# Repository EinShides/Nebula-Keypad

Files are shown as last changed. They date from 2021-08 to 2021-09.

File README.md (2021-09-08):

A small 3 key keypad with a rotary encoder and lcd display. The case is 3d printable and designed to work with m2 threaded inserts (4-5mm). Uses USB C, ESD protection, and GeonWorks tadpole mount. Currently a BOM is in the works.

THIS KEYPAD HAS NOT BEEN TESTED YET. 

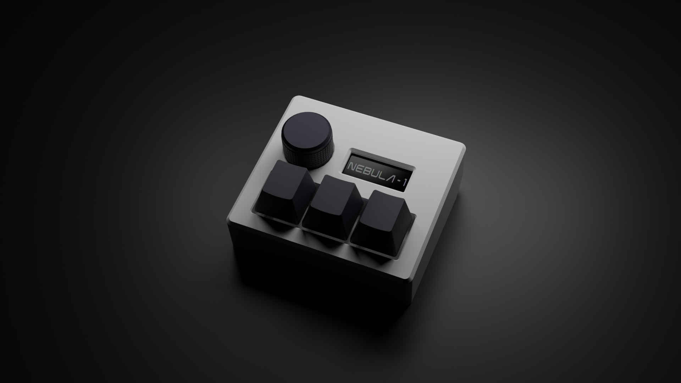
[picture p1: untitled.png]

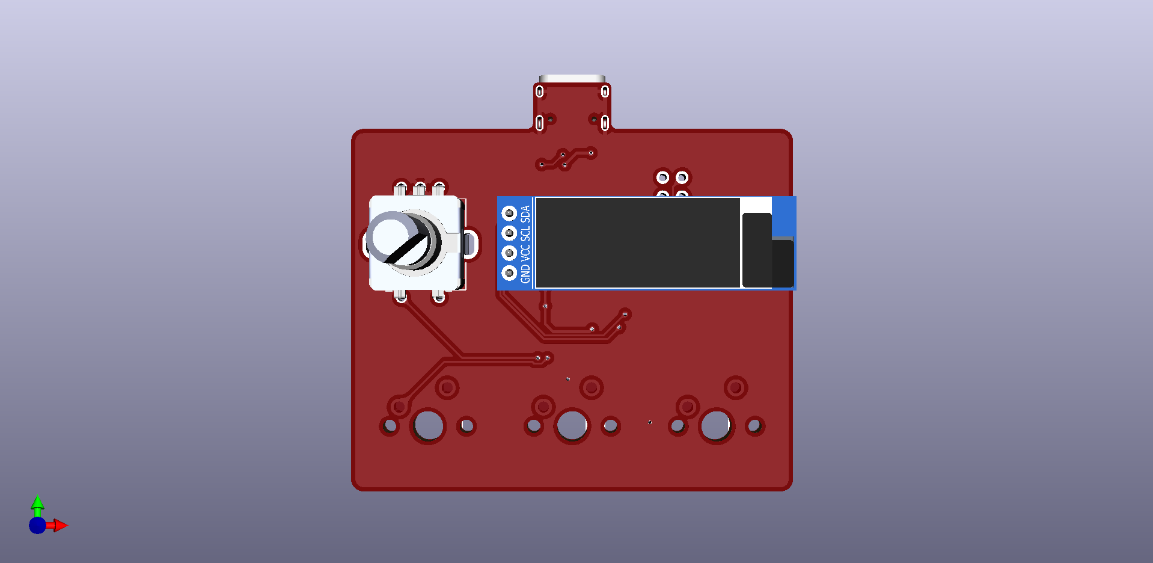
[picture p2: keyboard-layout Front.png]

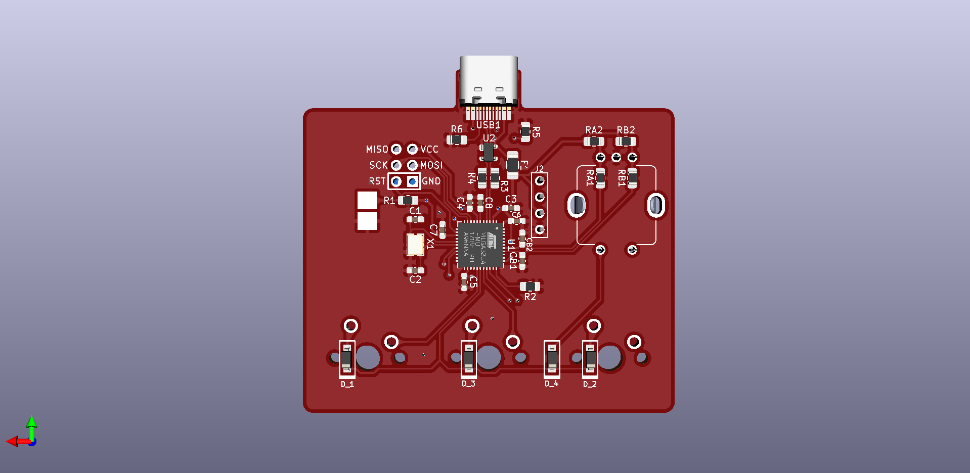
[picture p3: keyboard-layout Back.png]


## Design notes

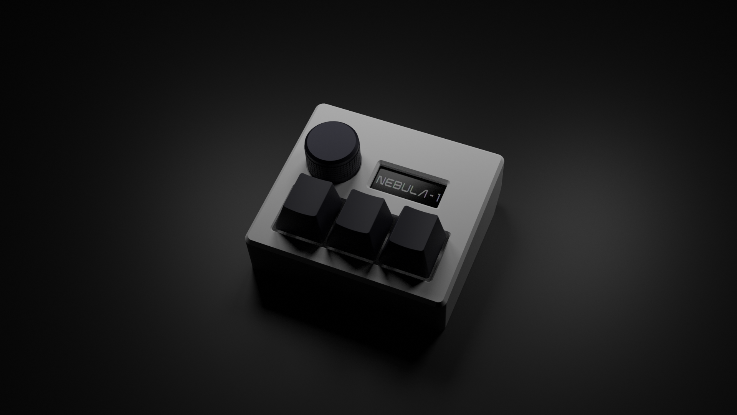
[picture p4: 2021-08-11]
Nebula.png

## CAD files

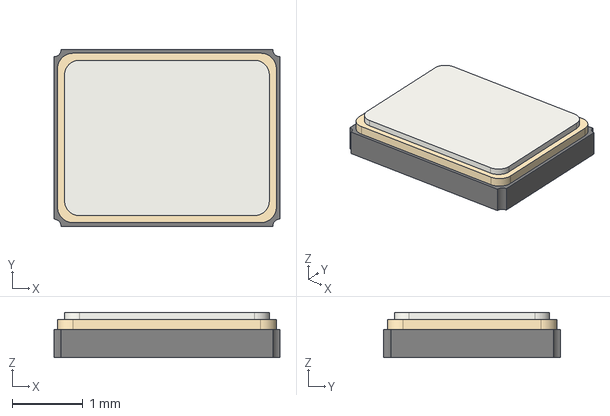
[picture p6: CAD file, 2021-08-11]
3d Component Models/Crystal_SMD_SeikoEpson_TSX3225-4Pin_3.2x2.5mm.step
3.20 x 2.50 x 0.64 mm

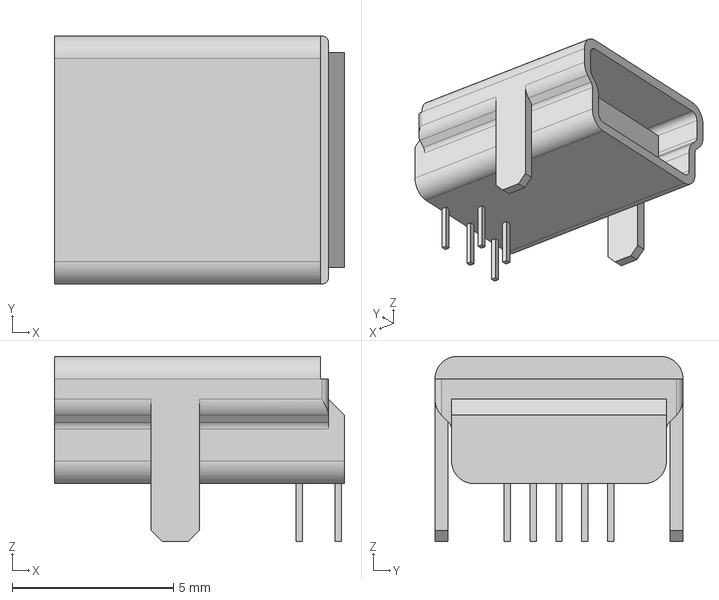
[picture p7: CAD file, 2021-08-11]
random-keyboard-parts.pretty-master/Molex-0548190519.step
9.00 x 7.70 x 5.75 mm

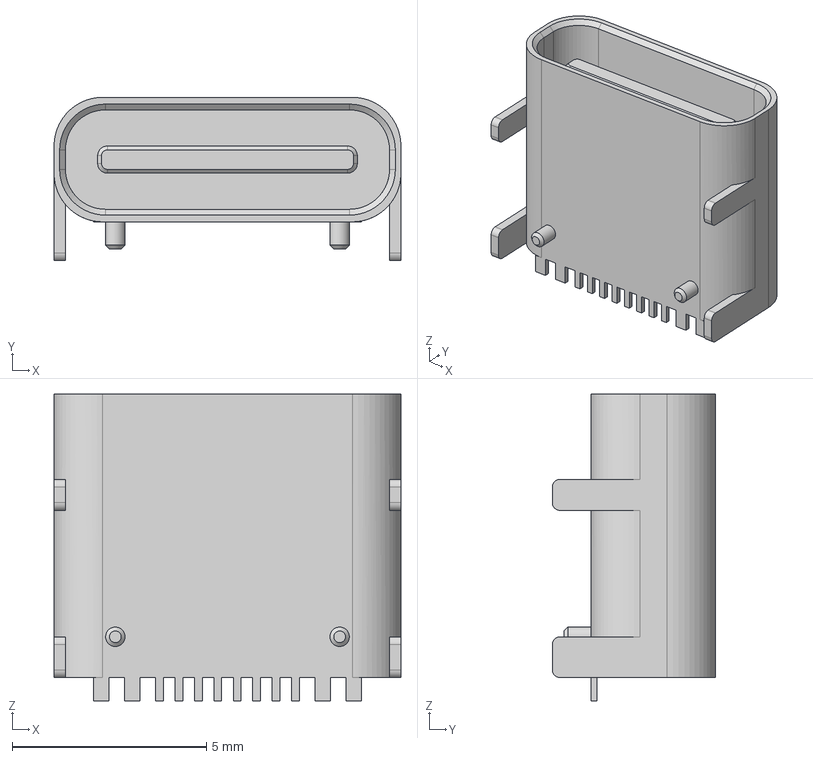
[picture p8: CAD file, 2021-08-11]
Type-C.pretty-master/HRO TYPE-C-31-M-12.step
8.94 x 4.21 x 7.90 mm

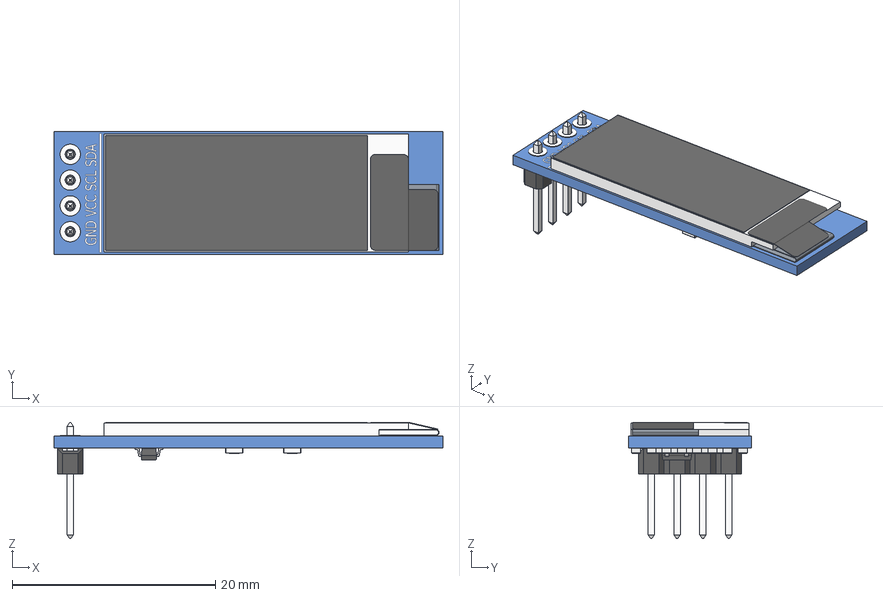
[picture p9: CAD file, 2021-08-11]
3d Component Models/OLED_0.91_128x32.stp
38.3 x 12.1 x 11.5 mm
OLED_0.91_128x32
Pin Header 4 x 1 TH 2.54mm Pitch
RESC-0603 x 13
2SD0601A

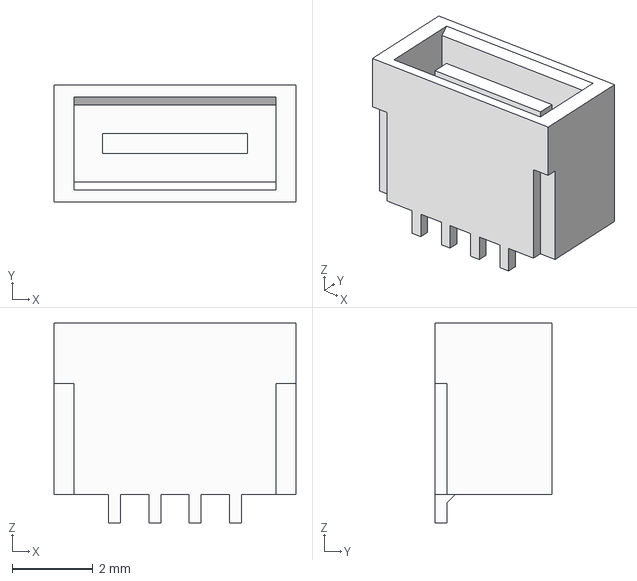
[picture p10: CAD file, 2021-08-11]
random-keyboard-parts.pretty-master/JST-SR-4.step
6.00 x 2.90 x 4.95 mm

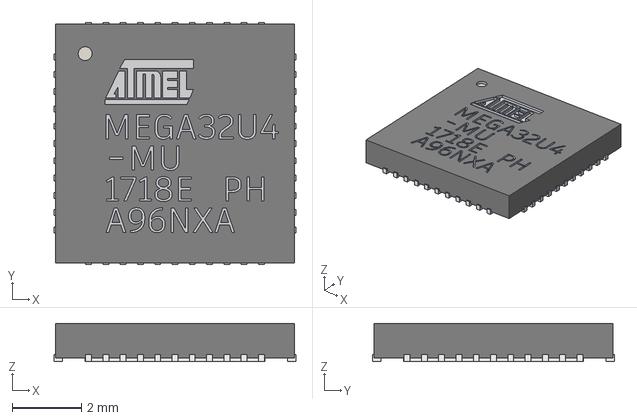
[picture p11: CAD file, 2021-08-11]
3d Component Models/QFN-44-1EP_7x7mm_P0.5mm_EP5.2x5.2mm.step
7.00 x 7.00 x 1.10 mm

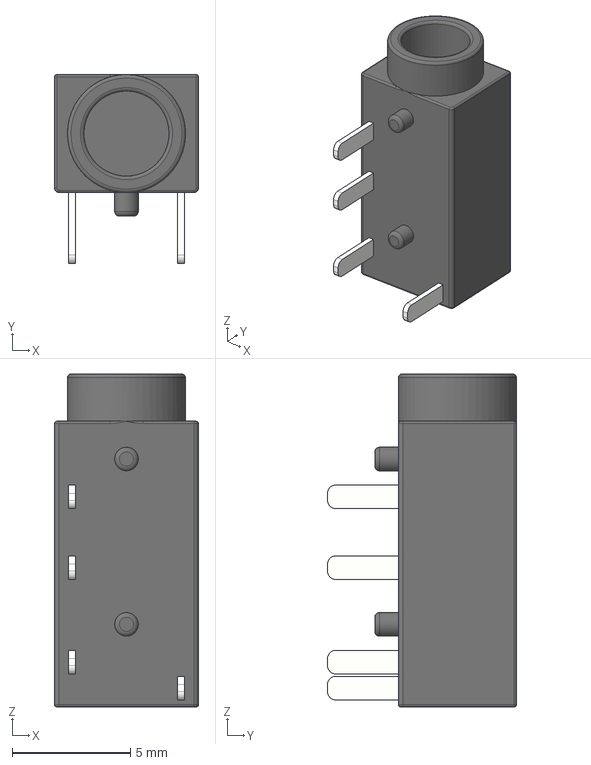
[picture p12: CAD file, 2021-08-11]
random-keyboard-parts.pretty-master/PJ-3200B.step
6.10 x 8.00 x 14.1 mm

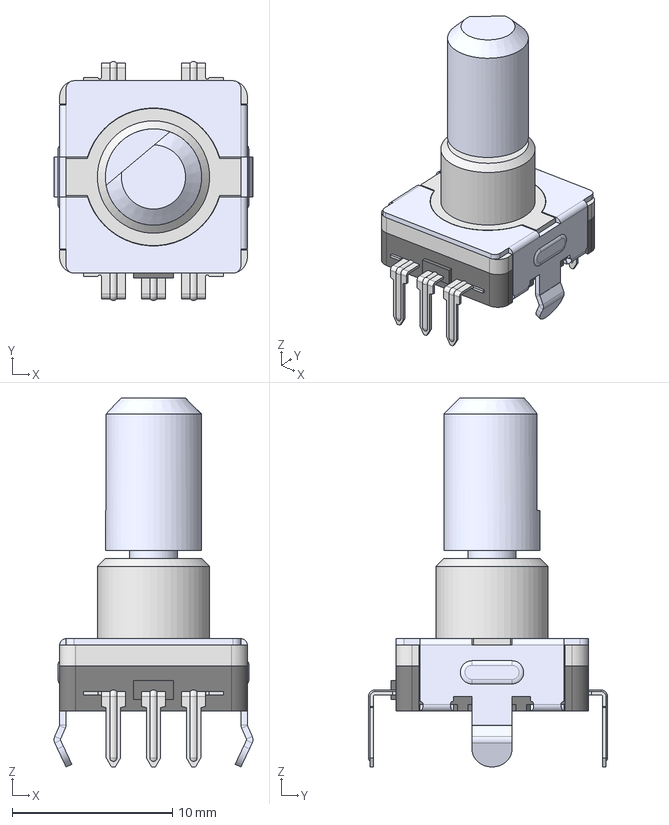
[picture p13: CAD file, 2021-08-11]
3d Component Models/EC11-THT-15F-black.step
12.4 x 14.9 x 23.0 mm
Lb5
15F
EC11-Housing-THT

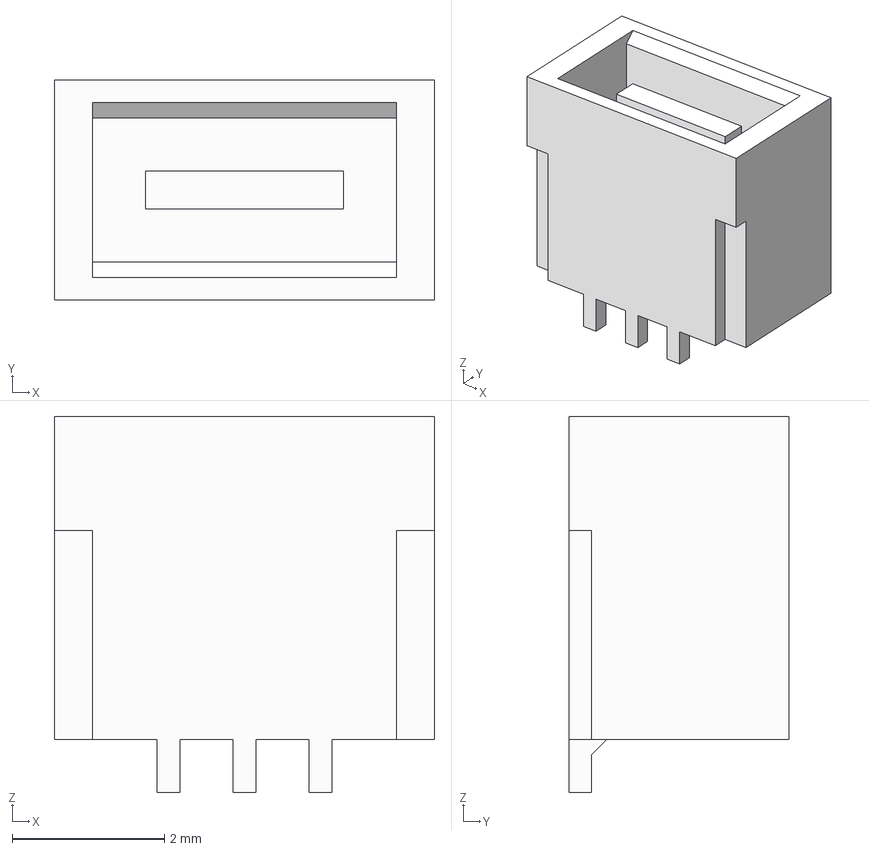
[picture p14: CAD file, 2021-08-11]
random-keyboard-parts.pretty-master/JST-SR-3.step
5.00 x 2.90 x 4.95 mm

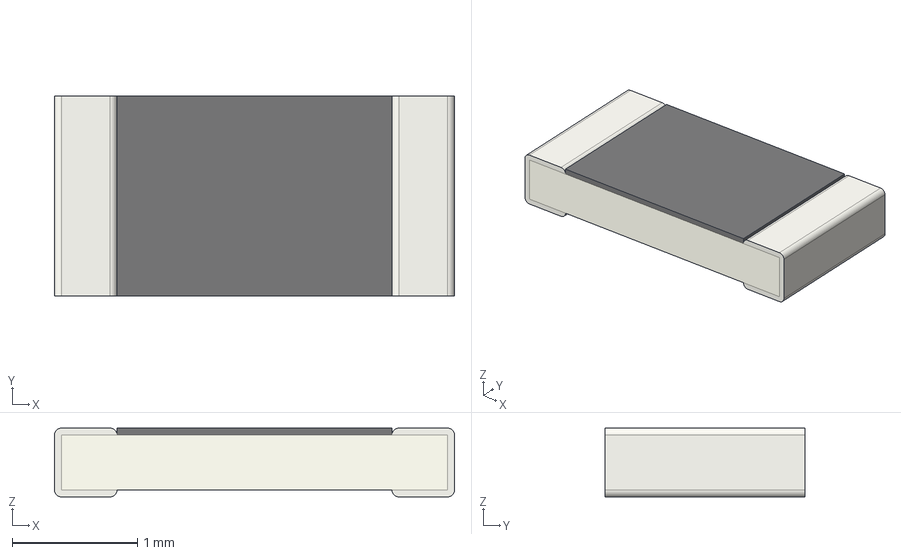
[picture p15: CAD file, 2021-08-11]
3d Component Models/Fuse_1206_3216Metric.step
3.20 x 1.60 x 0.55 mm

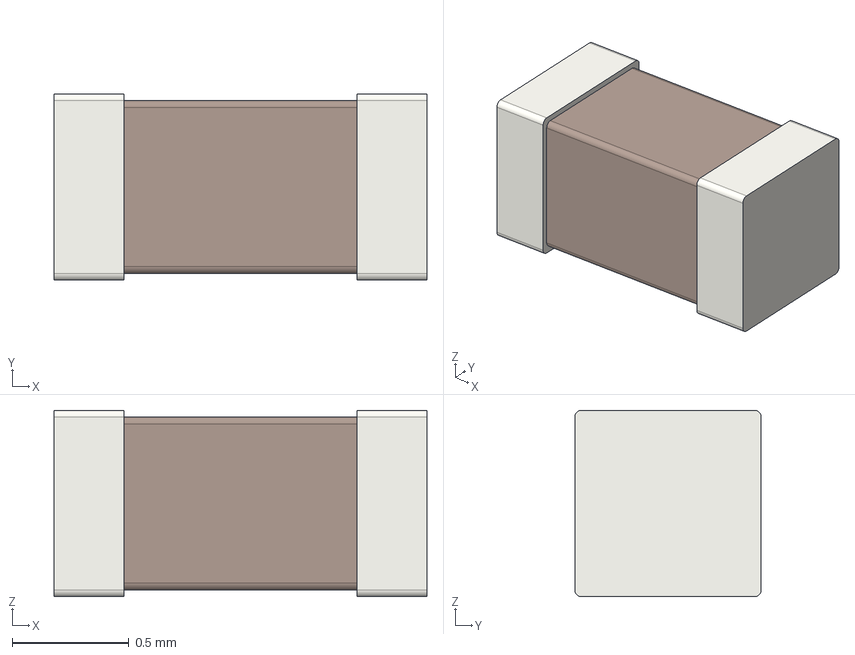
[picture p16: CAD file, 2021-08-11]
3d Component Models/C_0603_1608Metric.step
1.60 x 0.8 x 0.8 mm

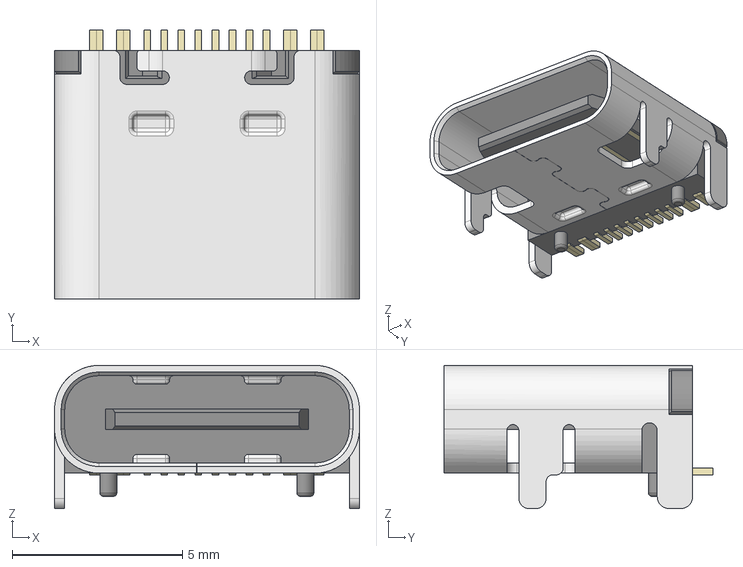
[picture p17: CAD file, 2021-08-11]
3d Component Models/HRO_TYPE-C-31-M-12.step
8.95 x 7.90 x 4.20 mm

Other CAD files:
kicad-footprints-master/Sources/Inductor_SMD/L_Coilcraft_LPS5030.FCStd
kicad-footprints-master/Sources/Package_LGA/Infineon_PG-LLGA-5-1.FCStd
kicad-footprints-master/Sources/Package_SON/X2SON-4_1x1mm_P0.65mm.fcstd
kicad-footprints-master/Sources/Package_TO_SOT_THT/sod-70_P5.08mm.fcstd
kicad-footprints-master/Sources/Inductor_SMD/L_Wuerth_WE-TPC-3816.FCStd
kicad-footprints-master/Sources/Package_TO_SOT_THT/sod-70.fcstd
3d Component Models/D_SOD-123.step
3d Component Models/R_0805_2012Metric.step

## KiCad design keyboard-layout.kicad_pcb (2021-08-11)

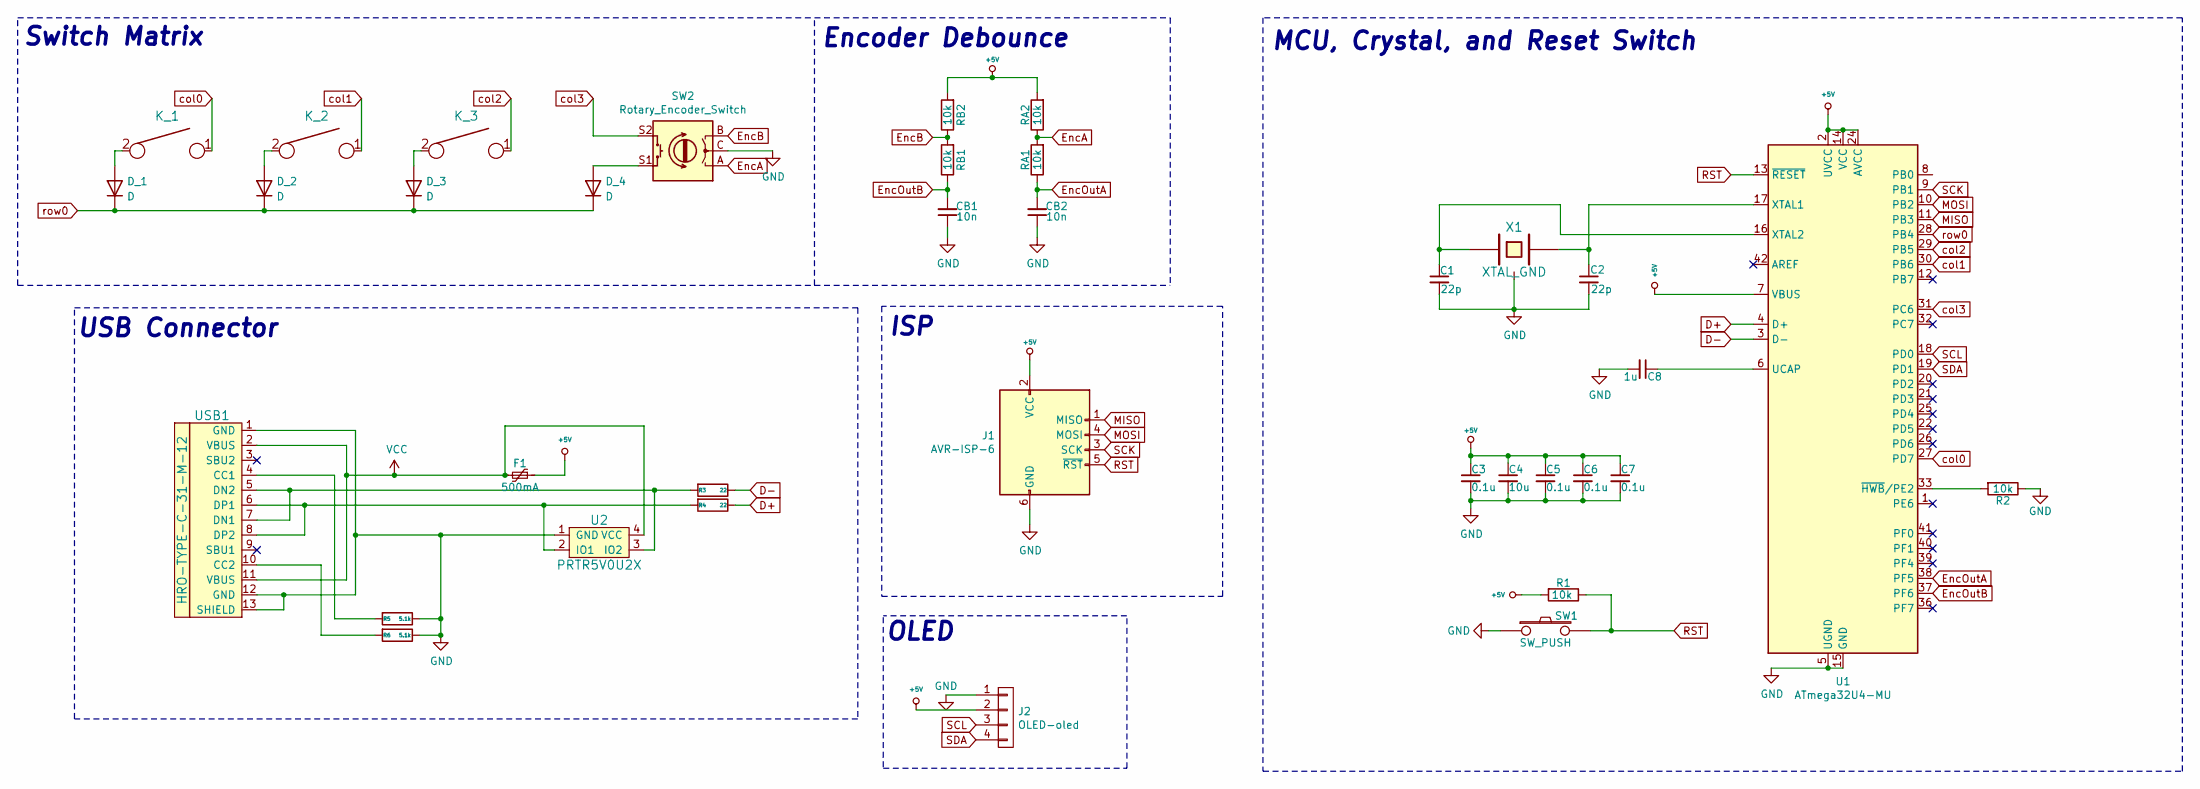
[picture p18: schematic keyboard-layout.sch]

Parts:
C1, C2: 22p; C_0603_1608Metric_Pad1.08x0.95mm_HandSolder; LCSC C1653
C3, C5, C6, C7: 0.1u; C_0603_1608Metric_Pad1.08x0.95mm_HandSolder; LCSC C24452
C4: 10u; C_0603_1608Metric_Pad1.08x0.95mm_HandSolder; LCSC C96446
C8: 1u; C_0603_1608Metric_Pad1.08x0.95mm_HandSolder; LCSC C15849
CB1, CB2: 10n; C_0603_1608Metric_Pad1.08x0.95mm_HandSolder; LCSC C15849
D_1, D_2, D_3, D_4: D; D_SOD123_hand; LCSC C64898
F1: 500mA; Fuse_1206_3216Metric_Pad1.42x1.75mm_HandSolder; LCSC C70076
J1: AVR-ISP-6; Reset_Pretty
J2: OLED-oled; OLED_4Pin
K_1, K_2, K_3: KEYSW; MXOnly-1U-NoLED
R1, R2: 10k; R_0805_2012Metric_Pad1.20x1.40mm_HandSolder; LCSC C17414
R3, R4: 22; R_0805_2012Metric_Pad1.20x1.40mm_HandSolder; LCSC C17561
R5, R6: 5.1k; R_0805_2012Metric_Pad1.20x1.40mm_HandSolder; LCSC C27834
RA1, RA2: 10k; R_0805_2012Metric_Pad1.20x1.40mm_HandSolder; LCSC C17414
RB1, RB2: 10k; R_0805_2012Metric_Pad1.20x1.40mm_HandSolder; LCSC C17414
SW1: SW_PUSH; Jumper-UserFriendly
SW2: Rotary_Encoder_Switch; ALPS_EC11E
U1: ATmega32U4-MU; QFN-44-1EP_7x7mm_P0.5mm_EP5.2x5.2mm; LCSC C45874
U2: PRTR5V0U2X; SOT143B; LCSC C316030
USB1: HRO-TYPE-C-31-M-12; HRO-TYPE-C-31-M-12-HandSoldering; LCSC C165948
X1: XTAL_GND; crystal_FA238-TSX3225; LCSC C89371

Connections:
+5V: C3.1, C4.1, C5.1, C6.1, C7.1, F1.1, J1.2 (VCC), J2.2, R1.2, RA2.2, RB2.2, U1.2 (UVCC), U1.7 (VBUS), U1.14 (VCC), U1.24 (AVCC), U1.34 (VCC), U1.44 (AVCC)
D+: R4.1, U1.4 (D+)
D-: R3.1, U1.3 (D-)
EncA: RA1.2, RA2.1, SW2.A
EncB: RB1.2, RB2.1, SW2.B
EncOutA: CB2.2, RA1.1, U1.38 (PF5)
EncOutB: CB1.2, RB1.1, U1.37 (PF6)
GND: C1.2, C2.2, C3.2, C4.2, C5.2, C6.2, C7.2, C8.2, CB1.1, CB2.1, J1.6 (GND), J2.1, R2.1, R5.1, R6.1, SW1.1, SW2.C, U1.5 (UGND), U1.15 (GND), U1.23 (GND), U1.35 (GND), U1.43 (GND), U1.45 (GND), U2.1 (GND), USB1.1 (GND), USB1.12 (GND), USB1.13 (SHIELD), X1.3
MISO: J1.1 (MISO), U1.11 (PB3)
MOSI: J1.4 (MOSI), U1.10 (PB2)
unnamed: C1.1, U1.16 (XTAL2), X1.1
unnamed: C2.1, U1.17 (XTAL1), X1.2
unnamed: C8.1, U1.6 (UCAP)
unnamed: D_1.2 (A), K_1.2
unnamed: D_2.2 (A), K_2.2
unnamed: D_3.2 (A), K_3.2
unnamed: D_4.2 (A), SW2.S1
unnamed: R2.2, U1.33 (~HWB~/PE2)
unnamed: R3.2, U2.3 (IO2), USB1.5 (DN2), USB1.7 (DN1)
unnamed: R4.2, U2.2 (IO1), USB1.6 (DP1), USB1.8 (DP2)
unnamed: R5.2, USB1.4 (CC1)
unnamed: R6.2, USB1.10 (CC2)
RST: J1.5 (~RST), R1.1, SW1.2, U1.13 (~RESET)
SCK: J1.3 (SCK), U1.9 (PB1)
SCL: J2.3, U1.18 (PD0)
SDA: J2.4, U1.19 (PD1)
VCC: F1.2, U2.4 (VCC), USB1.2 (VBUS), USB1.11 (VBUS)
col0: K_1.1, U1.27 (PD7)
col1: K_2.1, U1.30 (PB6)
col2: K_3.1, U1.29 (PB5)
col3: SW2.S2, U1.31 (PC6)
row0: D_1.1 (K), D_2.1 (K), D_3.1 (K), D_4.1 (K), U1.28 (PB4)

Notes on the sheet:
USB Connector
Encoder Debounce
Switch Matrix
ISP
MCU, Crystal, and Reset Switch
OLED

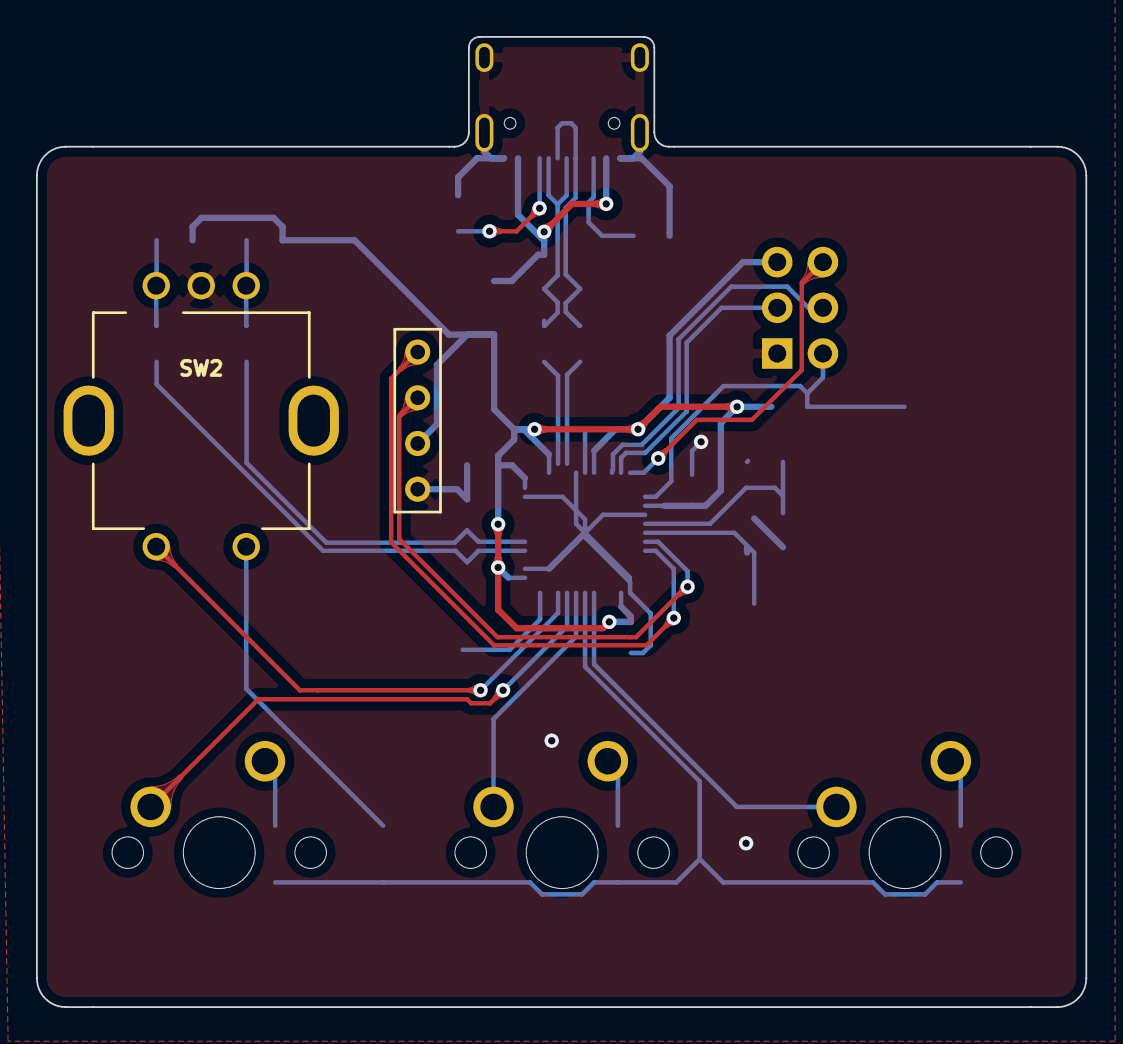
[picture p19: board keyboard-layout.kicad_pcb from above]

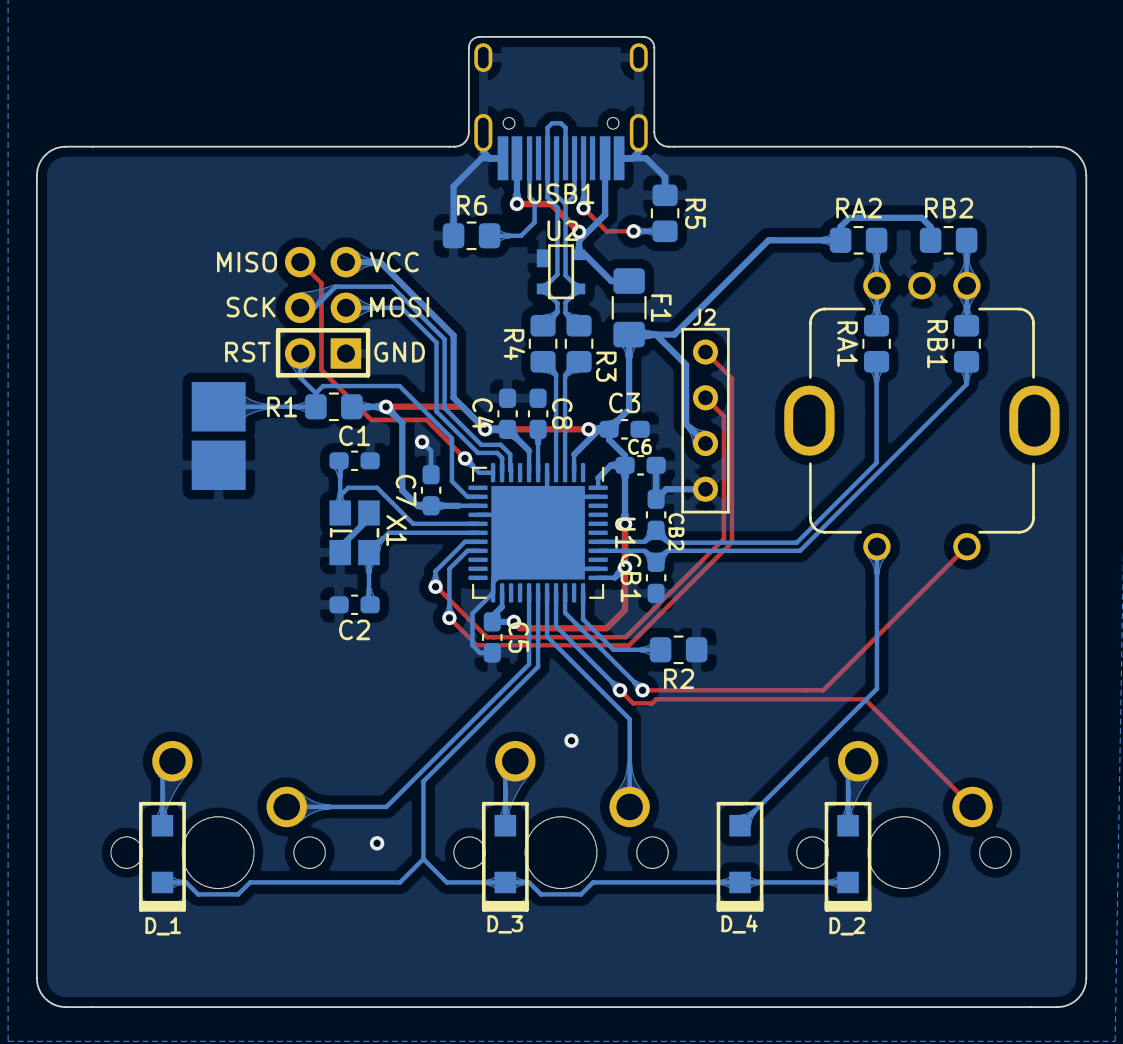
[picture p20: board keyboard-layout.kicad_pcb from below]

Board: 2 copper layers, 58.3 x 53.9 mm, 36 parts (32 on the bottom side), 32 nets.

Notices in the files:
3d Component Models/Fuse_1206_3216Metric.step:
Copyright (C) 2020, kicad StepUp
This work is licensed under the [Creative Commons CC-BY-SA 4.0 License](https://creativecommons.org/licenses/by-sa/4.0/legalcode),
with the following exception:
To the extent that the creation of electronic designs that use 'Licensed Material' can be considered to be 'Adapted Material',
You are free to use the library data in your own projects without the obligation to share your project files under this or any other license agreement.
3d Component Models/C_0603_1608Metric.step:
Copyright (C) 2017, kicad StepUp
